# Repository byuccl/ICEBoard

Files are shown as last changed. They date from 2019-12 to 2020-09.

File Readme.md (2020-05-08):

# ICE Board

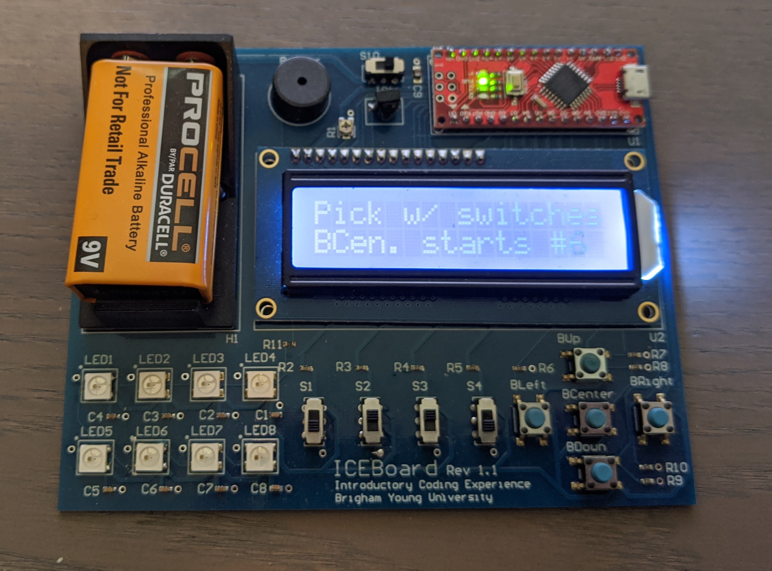
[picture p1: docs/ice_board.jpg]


This repository is for the "Introductory Coding Experience" (ICE) board. The purpose of this board is to provide a simple way for elementry aged students to interact with a simple embedded system by solving simple puzzles or playing simple games using a remote control and the ICE board. The board is based on the Arduino platform.

## Participants
  * Stephanie Ashby (stephoashby@gmail.com) - stephoa
  * Sharisse Poff (sharisse@bevan.us) - sharisse2
  * Elise Hasleton (elhas129@gmail.com) - 
  * Jeff Goeders (jgoeders@byu.edu) - jgoeders
  * Mike Wirthlin (wirthlin@byu.edu) - wirthlin

## Proposed directory structure
  * 'hw' directory for all of the hardware. Include power calculation  spreadsheets.
    * 'pcb' PCB information
    * 'datasheets' : component data sheets,
  * 'src' directory for the Arduino source
  * 'doc' directory for documentation and materials for students

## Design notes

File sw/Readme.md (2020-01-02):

# ICEBoard Software Documents
| Arduino Pin | Type  | Use |
| --- | ----  | --- |
|  1 | D1/TX | Tactile Switch (S5) |
|  2 | D0/RX | IR Receiver (IR1) |
|  3 | RESET |
|  4 | GND |
|  5 | D2 |
|  6 | D3 | NeoPixel (D1 - D8 are controlled with this pin) |
|  7 | D4 | Slide Switch (S1) |
|  8 | D5 | Slide Switch (S2) |
|  9 | D6 | Slide Switch (S3) |
| 10 | D7 | Slide Switch (S4) |
| 11 | D8 |
| 12 | D9 | Buzzer (B1) |
| 13 | D10 | Tactile Switch (S7) |
| 14 | D11 | Tactile Switch (S6) |
| 15 | D12 | Tactile Switch (S8) |
| 16 | D13 | Tactile Switch (S9) |
| 17 | 3V3 | Powers IR Receiver (IR1) |
| 18 | AREF  |
| 19 | A0 | LCD (pin D7) |
| 20 | A1 | LCD (pin D6) |
| 21 | A2 | LCD (pin D5) |
| 22 | A3 | LCD (pin D4) |
| 23 | A4 | LCD (enable pin) |
| 24 | A5 | LCD (reset pin) |
| 25 | A6 |
| 26 | A7 |
| 27 | 5V | Powers neopixels, LCD screen, slide switches, tactile switches (D1 - D8, U2, S1 - S9) |
| 28 | RESET |
| 29 | GND |
| 30 | VIN | Connects to 9V battery |

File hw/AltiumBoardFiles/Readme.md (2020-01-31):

# Revision changes:
## Rev 1.1
- Fixed NeoPixel footprint (Rev 1.0 had the footprint oriented upside down)
- Added 470 ohm resistor between Arduino and first NeoPixel
- Replaced slide switches with larger slide switches
- Added power switch
- Renamed B1 as Buzzer, D1 - D8 as LED1 - LED8, S5 - S9 as BUp, BDown, etc.
- Moved IR1 from pin D0 to pin D2 and S5 from pin D1 to pin D8 to avoid interference with the UART
- Added screw holes for battery holder

# Board Design notes on answered questions:
- There is a software way to turn the NeoPixels on part way so we do not need resistors to dim them.
- All of the traces are routed on the top of the board so the bottom layer can be a ground plane.
- The Arduino cannot supply enough current to have all the LEDs on at full power at the same time.  Make sure software accounts for that.
- The datasheet says that the LCD screen takes 40mA for logic and 30mA for the backlight.  Stephanie measured the currents to be 19mA and 0.6mA.
- [This](https://www.ftdichip.com/Support/Documents/DataSheets/ICs/DS_FT232R.pdf) is the datasheet for the chip on the Arduino Nano that supplies 3.3V.  It looks like the 3.3V pin can supply 50mA.
- It doesn't matter if traces are routed under parts for this board.
- We should not need to specify board thickness in the project's Layer Stack Manager.  It sounds like board thickness is specified separately when ordering the board.
- A 9V battery typically gets up to 500 mAh, which means it wouldn't last very long if we're drawing 500mA at once.  However, if we aren't using all the LEDs at the same time or at maximum brightness it would probably last longer.  Most of what I read suggested drawing less than 100mA, but it sounded like this is just a suggestion to get a longer battery life.  [Here](http://www.techlib.com/reference/batteries.html) is a table I found.
- Usually the buttons will take current when they are pressed if they use a pull up architecture.  Other than a brief transient when the switch is changed, the switches usually don't take any current that is worth keeping track of.

# Board Design questions:
- The LCD instructions say not to connect 5V directly to the backlight terminal.  The part we have probably has a series resistor to account for that, but I read that the backlight needs 3.2V so I wonder if there is a way to power it with the 3.3V pin?  Just a thought if that could help us move some of the current off of the 5V pin.  Stephanie measured the LCD currents and sent me this response: "Measuring the backlight, it was about 19 mA and .6 mA (but that one is with the 1k resistor so...). In any case, I don't know why it is so low, but that is what the multimeter says."  If it really is that low that will help with power consumption as well.
  - I looked into this and I can't find anywhere what resistor is used to limit the voltage to the LCD backlight.
- Is there a better option for RGB LEDs that uses less current?

# Ideas and options:
## RGB LED alternatives to NeoPixels:
1) There are plenty of RGB LEDs that take around 20mA current for each color but they require either four or six logic pins to control.
2) Can use MAX 7219 to control up to 64 LEDs with three Arduino pins: clock, data, latch (330mA)
- Looks like this might only work with an LED matrix
- https://tronixstuff.com/2013/10/11/tutorial-arduino-max7219-led-display-driver-ic/
- brainy-bits.com/how-to-control-max7219-led-matrix/
3) The other programmable LEDs I found also take 50 – 60mA
- https://www.amazon.com/ALITOVE-WS2812B-Individually-Addressable-Waterproof/dp/B00ZHB9M6A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
4) Could use transistors and PWM to control individual LEDS – seems more complicated
- https://arduino.stackexchange.com/questions/29367/individual-control-of-multiple-rgb-leds

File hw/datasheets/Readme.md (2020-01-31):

# ICEBoard Datasheets

## Components

### Arduino Nano

- Purpose: This is the ICEBoard processor.  All of the other components on the board are powered and software-controlled by the Arduino Nano.
- Description: 
- [Website](https://store.arduino.cc/usa/arduino-nano)
- [Datasheet](./nano-user-manual.pdf)
- Notes:

### LCD

- Purpose: 
- Description: Adafruit standard LCD 16x2 + extras - white on blue, through hole
- [Website](https://www.adafruit.com/product/181)
- [Datasheet](./TC1602A-09T.pdf)
- Notes: We are using the TC1602A-09T because it pulls significantly less current than the TC1602A-01T.  The [TC1602A-01T datasheet](./TC1602A-01T) is included in this folder for reference because it includes page 4 (the part drawing), which the TC1602A-09T datasheet is missing.

### NeoPixel

- Purpose: 
- Description: NeoPixel 5050 RGB LED with Integrated Driver Chip, surface mount
- [Website](https://www.adafruit.com/product/1655)
- [Datasheet](./SK6812_LED_datasheet.pdf)
- Notes: NeoPixels require only one digital pin for an entire chain.  Each NeoPixel requires up to 60mA of current.

### Slide Switch

- Purpose: 
- Description: Switch Slide SPDT 300mA 6V, through hole
- [Website](https://www.digikey.com/product-detail/en/apem-inc/MHSS1104/679-1848-ND/1795408)
- [Datasheet](./MHSS1104_drawing.pdf)
- Notes: Rev. 1.0 used the JS202011SCQN part instead.  Its [datasheet](./JS202011SCQN_datasheet.pdf) is still in this folder.

### Tactile Switch

- Purpose: 
- Description: Switch Tactile SPST-NO 0.05A 12V, surface mount
- [Website](https://www.digikey.com/products/en?keywords=CKN10889CT-ND)
- [Datasheet](./PTS645_datasheet.pdf)
- Notes: The footprint will work for a few different colors of push buttons.

### IR Receiver

- Purpose: 
- Description: Sensor Remote Rec 40.0kHz 45M, through hole
- [Website](https://www.digikey.com/products/en?keywords=TSOP38240-ND)
- [Datasheet](./tsop382_datasheet.pdf)
- Notes: This part comes in different frequencies.

### Battery Holder

- Purpose: 
- Description: Battery Holder 9V PC Pin, through hole
- [Website](https://www.digikey.com/products/en?keywords=BH9V-PC-ND)
- [Datasheet](./BH9VPC-datasheet.pdf)
- Notes: 

### Buzzer

- Purpose: 
- Description: Piezo Transducer 5V 5mA 4kHz 75dB@5V, through hole
- [Website](https://www.digikey.com/products/en?keywords=2104-TP124005-2CT-ND)
- [Datasheet](./TP124005-2_drawing.pdf)
- Notes: 

### Potentiometer

- Purpose:
- Description: Trimmer 10k Ohm 0.1W J Lead Top, surface mount
- [Website](https://www.digikey.com/product-detail/en/bourns-inc/TC33X-2-103E/TC33X-103ECT-ND/612911)
- [Datasheet](./tc33_datasheet.pdf)
- Notes: The -2 part has a rotational stop and the -1 part has continous rotation.  The footprints are identical.

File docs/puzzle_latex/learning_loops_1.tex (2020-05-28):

\puzzle{4}{Learning Loops 1}{Easy}

\setlength{\parskip}{0em}
\noindent
\while{\bdown \pressed}
    \assign{\led{1}}{RED}
    \wait{3.0}
    \assign{\led{1}}{OFF}
    \wait{1.0}

    \gap

    \assign{\led{1}}{RED}
    \wait{3.0}
    \assign{\led{1}}{OFF}
    \wait{1.0}

    \gap

    \assign{\led{1}}{RED}
    \wait{3.0}
    \assign{\led{1}}{OFF}
    \wait{1.0}

\whileend

\programend

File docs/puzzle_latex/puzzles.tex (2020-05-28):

\documentclass[]{article}

\usepackage[margin=1in]{geometry}
\usepackage{fmtcount}
\usepackage{xcolor}
\usepackage{lmodern}

\newcommand{\puzzle}[3]{%
    \noindent
    \rule{\textwidth}{2pt}   
    \begin{center} 
        { \large Program \##1: #2  \\ \vspace{0.05in}
        Set switches to: \padzeroes[4]\binarynum{#1} \\ \vspace{0.05in}
        (\textit{#3}) }
    \end{center}   
    \rule{\textwidth}{2pt}   %
}

\newcommand{\incindent}{\addtolength\parindent{20pt}}
\newcommand{\decindent}{\addtolength\parindent{-20pt}}

\newcommand{\gap}{\vspace{0.1in}}

\newcommand{\while}[1]{{\color{blue}\textbf{while: }}#1 \{ \incindent \par}
\newcommand{\whileend}{\decindent \par\}}

\newcommand{\wait}[1]{\textbf{wait} #1 seconds \par}

\newcommand{\assign}[2]{ #1 $\leftarrow$ #2 \par}

\newcommand{\lcd}{{\color{purple}\textbf{LCD screen}}}
\newcommand{\printtolcd}[1]{Print `#1' to \lcd}

\newcommand{\bdown}{{\color{purple}\textbf{BDown }}}

\newcommand{\led}[1]{{\color{purple}\textbf{led#1}}}

\newcommand{\pressed}{is pressed}
\newcommand{\notpressed}{is not pressed}

\newcommand{\programend}{\gap \gap Play beep sound \\ \printtolcd{You win} }
\begin{document}

\ttfamily
\setlength{\parindent}{0pt}

\input{learning_loops_1.tex}

\end{document}

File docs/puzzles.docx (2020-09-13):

# Puzzle #1

while [led1, led2, led3, led4] is NOT [BLUE, YELLOW, GREEN, PURPLE]:

while BCenter is not pressed:

if S1 is up:

led8.red = ON

else:

led8.red = OFF

if S2 is up:

led8.green = ON

else:

led8.green = OFF

if S3 is up:

led8.blue = ON

else:

led8.blue = OFF

led4 = led2

led2 = led3

led3 = led1

led0 = led8

while BCenter is pressed:

do nothing

Play beep sound

Print “You win” on LCD screen

# Puzzle #2

A = 0;

B = 0;

Print A, “+”, B, “=”, A+B on LCD screen

while A + B != 10 or A < 2 or B < 2:

if BUp is pressed and BRight is pressed:

A = A + 1

clear LCD screen

led1 = BLUE;

delay(1.0);

led1 = OFF;

Print A, “+”, B, “=”, A+B on LCD screen

if BCenter is pressed and BDown is pressed:

B = B + 1

clear LCD screen

led8 = GREEN;

delay(1.0);

led8 = OFF;

Print A, “+”, B, “=”, A+B on LCD screen

delay(1.0);

Play beep sound

Print “You win” on LCD screen

# Puzzle #3

loop {

led1 = YELLOW

wait 5.0 seconds

led1 = OFF

if S4 is UP:

led1 = RED;

loop {

if S4 is DOWN:

exit loop

}

else:

wait 0.5 seconds

if S4 is UP:

exit loop

}

Play beep sound

Print “You win” on LCD screen

# #4 (0100) – Learning Loops 1

while BDown is not pressed:

led1 = RED

wait 3.0 seconds

led1 = OFF

wait 1.0 seconds

led1 = BLUE

wait 3.0 seconds

led1 = OFF

wait 1.0 seconds

led1 = GREEN

wait 3.0 seconds

led1 = OFF

wait 1.0 seconds

Play beep sound

Print “You win” on LCD screen

Question: Why doesn’t the program end as soon as you press BDown?

# #5 (0101) – Learning Ifs 1

loop forever:

if BLeft is pressed:

led5 = RED

led6 = ORANGE

led7 = YELLOW

if BRight is pressed:

exit loop

else

led5 = BLUE

led6 = AQUA

led7 = GREEN

Play beep sound

Print “You win” on LCD screen

Question: Why doesn’t the program end if you only press BRight?

# #6 (0110) – Learning Loops 2

X = 0

led1 = GREEN

while X < 10:

Wait for BCenter to be pressed

Print “X is ” on LCD screen

Print X on LCD screen

LED2 = LED3

LED3 = LED4

LED4 = LED8

LED8 = LED7

LED7 = LED6

LED6 = LED5

LED5 = LED1

LED1 = OFF

X = X + 1

Play beep sound

Print “You win” on LCD screen

Question: What’s the value of X when the program ends?

Challenge: Explain why two LEDs turn on at the same time, but only once.

# #7 (0111) – Learning Loops 3

led1 = GREEN

led2 = GREEN

led3 = GREEN

led4 = GREEN

BUp = 1;

BRight = 2;

BDown = 3;

BLeft = 4;

button = (press a button)

for (button) number of times, turn on one LED

led4 = PURPLE

led3 = PURPLE

led2 = PURPLE

led1 = PURPLE

Play beep sound

Print “You win” on LCD screen

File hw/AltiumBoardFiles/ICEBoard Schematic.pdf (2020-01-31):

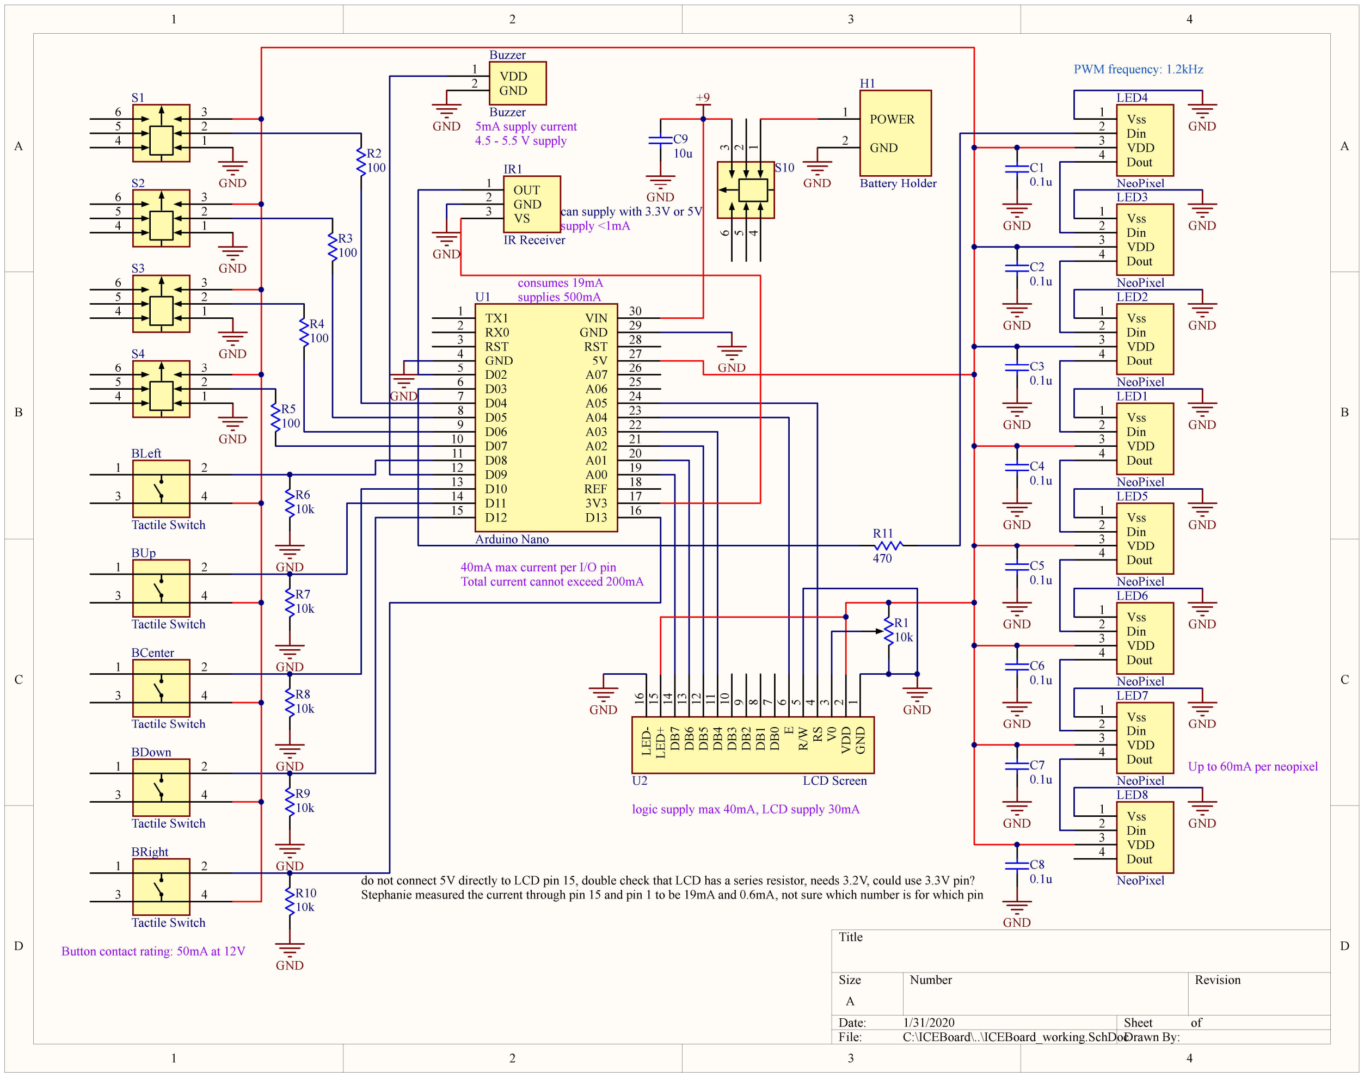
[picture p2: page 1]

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
Title

Size | Number | | Revision
A
Date: | 1/31/2020 | Sheet | of
File: | C:\ICEBoard\..\ICEBoard_working.SchDocDrawn By:
VIN | 30
GND | 29
RST | 28
5V | 27
A07 | 26
A06 | 25
A05 | 24
A04 | 23
A03 | 22
A02 | 21
A01 | 20
A00 | 19
REF | 18
3V3 | 17
D13 | 16 D12 15

TX1 1
RX0 2

GND 4
D02 5
D03 6

RST 3

D04 7
D05 8
D06 9
D07 10
D08 11
D10 13 D09 12

D11 14

U1

Arduino Nano

GND

+9
Vss 1
Din 2

Dout 4

VDD 3

LED4

NeoPixel

Vss 1
Din 2

Dout 4

VDD 3

LED3

NeoPixel

GND

GND

logic supply max 40mA, LCD supply 30mA

do not connect 5V directly to LCD pin 15, double check that LCD has a series resistor, needs 3.2V, could use 3.3V pin?

PWM frequency: 1.2kHz

40mA max current per I/O pin

consumes 19mA

Up to 60mA per neopixel LED⁻ ¹⁶ LED⁺ ¹⁵ | GND

## 1 VDD

### 2 RS

## 4 R/W

### 5 E

### 6 V0

### 3 DB0

## 7 DB1

## 8 DB2

### 9 DB3 10 DB4 11 DB6 13 DB5 12 DB7 14

U2 | LCD Screen

GND

Button contact rating: 50mA at 12V

Vss 1
Din 2

Dout 4

VDD 3

LED2

NeoPixel

Vss 1
Din 2

Dout 4

VDD 3

LED1

NeoPixel

GND

GND

5mA supply current
4.5 - 5.5 V supply

Vss 1
Din 2

Dout 4

VDD 3

LED5

NeoPixel

Vss 1
Din 2

Dout 4

VDD 3

LED6

NeoPixel

Vss 1
Din 2

Dout 4

VDD 3

LED7

NeoPixel

Vss 1
Din 2

Dout 4

VDD 3

LED8

NeoPixel

GND

GND

GND

GND

POWER 1

GND 2

H1

GND Battery Holder

GND

C1
0.1u

C2
0.1u

C3
0.1u

C4
0.1u

C5
0.1u

C6
0.1u

C7
0.1u

C8
0.1u

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
VDD 1
GND 2

Buzzer

Buzzer
GND

can supply with 3.3V or 5V

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
supplies 500mA

R4
100

R5
100

R2
100

R3
100 GND

supply <1mA

OUT 1
GND 2
VS 3

IR1

IR Receiver

Stephanie measured the current through pin 15 and pin 1 to be 19mA and 0.6mA, not sure which number is for which pin

Total current cannot exceed 200mA

GND

GND

GND

GND

1

3 4

2

BLeft

Tactile Switch

1

3 4

2

BUp

Tactile Switch

1

3 4

2

BCenter

Tactile Switch

1

3 4

2

BDown

Tactile Switch

1

3 4

2

BRight

Tactile Switch

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
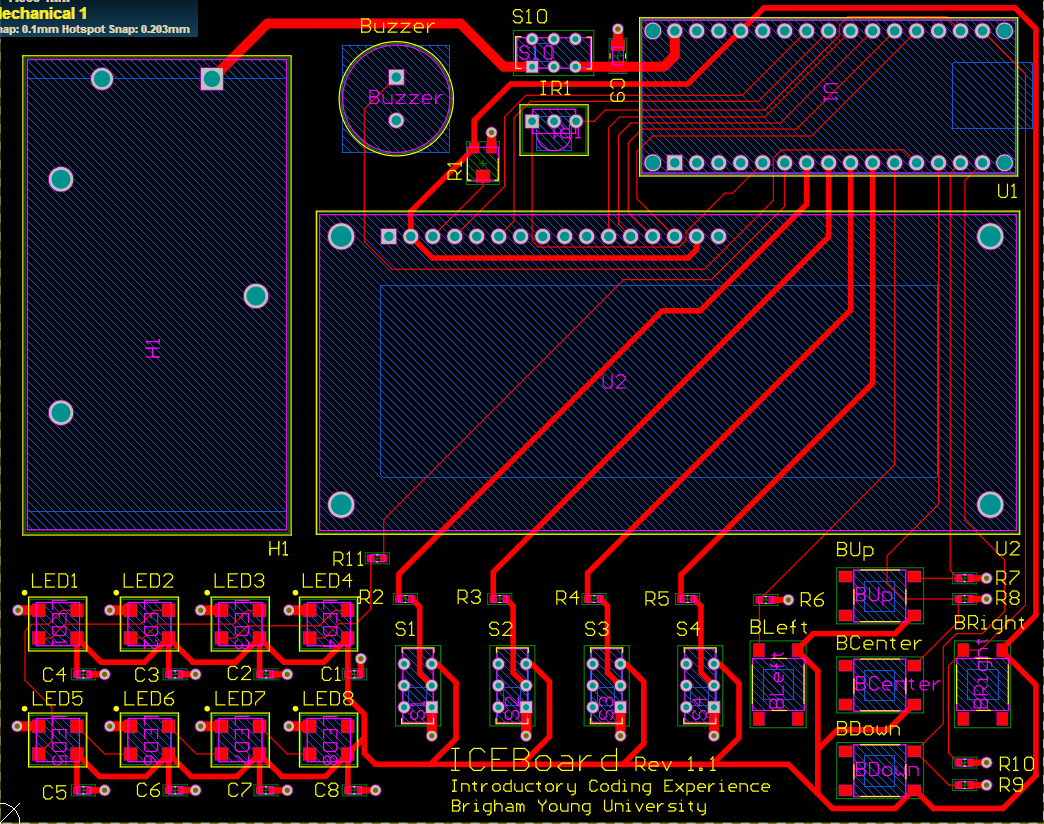
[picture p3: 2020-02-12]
hw/AltiumBoardFiles/ICEBoard PCB Layout (ground plane hidden).PNG

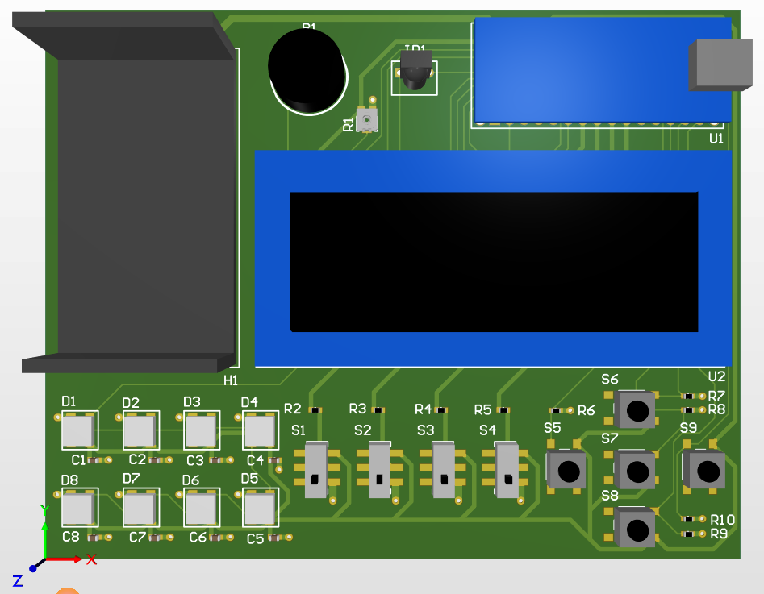
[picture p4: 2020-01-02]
hw/AltiumBoardFiles/ICEBoard PCB Layout 3D-1.PNG

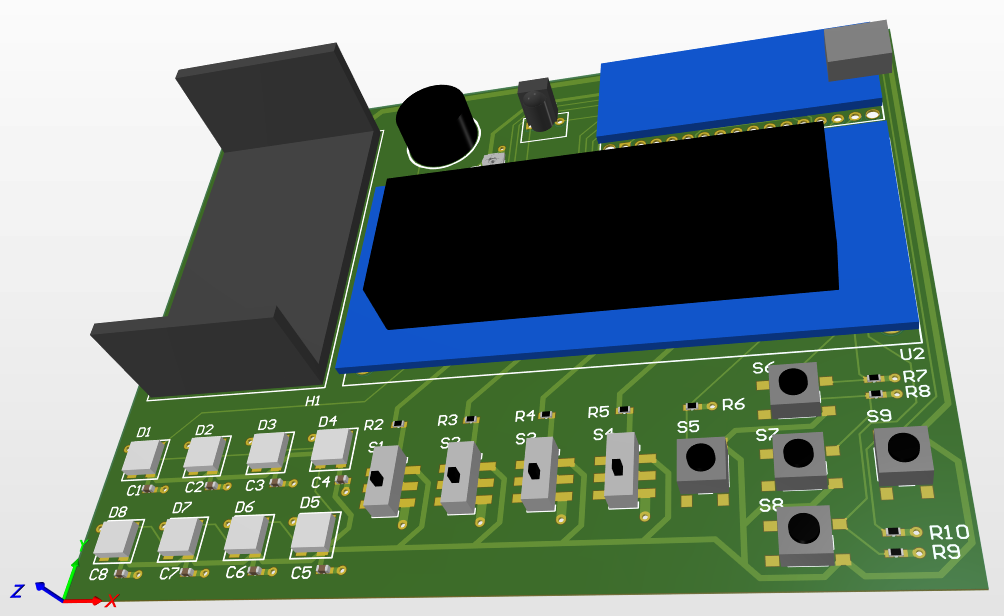
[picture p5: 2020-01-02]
hw/AltiumBoardFiles/ICEBoard PCB Layout 3D-2.PNG

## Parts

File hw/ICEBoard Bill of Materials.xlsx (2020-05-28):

Type | Value | Manufacturer | Manufacturer Part Number | Description | Where Used | Unit Price | Quantity | Total Price | Digi-Key Part Number | Link
Arduino | Nano | Arduino |  |  | U1 | $4.00 | 1 | $4.00 | -
LCD screen |  | Adafruit |  | Standard LCD 16x2 + extras - white on blue | U2 | $9.95 | 1 | $9.95 | 1528-1502-ND | https://www.digikey.com/product-detail/en/adafruit-industries-llc/181/1528-1502-ND/5774228 | $248.75
RGB LED |  | Adafruit |  | NeoPixel 5050 RGB LED with Integrated Driver Chip - 10 pack | LED1, LED2, LED3, LED4, LED5, LED6, LED7, LED8 | $0.45 | 8 | $3.60 | 1528-1104-ND | https://www.digikey.com/product-detail/en/adafruit-industries-llc/1655/1528-1104-ND/5154679 | $90.00
Slide Switch | SPDT | APEM | MHSS1104 | SWITCH SLIDE SPDT 300MA 6V | S1, S2, S3, S4, S10 | $0.49 | 5 | $2.48 | 679-1848-ND | https://www.digikey.com/product-detail/en/MHSS1104/679-1848-ND/1795408/?itemSeq=319915833 | $61.88
Tactile Switch | SPST-NO | C&K | PTS645SM50SMTR92 LFS | SWITCH TACTILE SPST-NO 0.05A 12V | BLeft, BUp, BCenter, BDown, BRight | $0.22 | 5 | $1.10 | CKN10889CT-ND | https://www.digikey.com/product-detail/en/c-k/PTS645SM50SMTR92-LFS/CKN10889CT-ND/3861376 | $27.47
IR Receiver | 40kHz | Vishay | TSOP38238 | SENSOR REMOTE REC 40.0KHz 45M | IR1 | $0.76 | 1 | $0.76 | TSOP38240-ND | https://www.digikey.com/products/en?keywords=TSOP38240-ND | $18.90
Battery Holder | 9V holder | MPD | BH9VPC | BATTERY HOLDER 9V PC PIN | H1 | $1.70 | 1 | $1.70 | BH9V-PC-ND | https://www.digikey.com/products/en?keywords=BH9VPC | $42.43
Resistor | 10k | Bourns | TC33X-2-103E | TRIMMER 10K OHM 0.1W J LEAD TOP | R1 | $0.25 | 1 | $0.25 | TC33X-103ECT-ND | https://www.digikey.com/product-detail/en/bourns-inc/TC33X-2-103E/TC33X-103ECT-ND/612911 | $6.26
Resistor | 100 | Yageo | RC0603FR-07100RL | RES SMD 100 OHM 1% 1/10W 0603 | R2, R3, R4, R5 | $0.01 | 4 | $0.04 | 311-100HRCT-ND | https://www.digikey.com/product-detail/en/%E5%9E%88%ED%9B%87/RC0603FR-07100RL/311-100HRCT-ND/729835 | $0.94
Resistor | 10k | Yageo | RC0603FR-0710KL | RES SMD 10K OHM 1% 1/10W 0603 | R6, R7, R8, R9, R10 | $0.02 | 5 | $0.11 | 311-10.0KHRCT-ND | https://www.digikey.com/product-detail/en/%E5%9E%88%ED%9B%87/RC0603FR-0710KL/311-10-0KHRCT-ND/729827 | $2.88
Resistor | 470 | Yageo | RC0603FR-07470RL | RES SMD 470 OHM 1% 1/10W 0603 | R11 | $0.02 | 1 | $0.02 | 311-470HRCT-ND | https://www.digikey.com/product-detail/en/yageo/RC0603FR-07470RL/311-470HRCT-ND/730203 | $0.57
Capacitor | 0.1u | Kemet | C0603C104M4RACTU | CAP CER 0.1UF 16V X7R 0603 | C1, C2, C3, C4, C5, C6, C7, C8 | $0.02 | 8 | $0.13 | 399-1099-1-ND | https://www.digikey.com/product-detail/en/kemet/C0603C104M4RACTU/399-1099-1-ND/411374 | $3.22
Capacitor | 10u | Kemet | CL21A106KPFNNNG | CAP CER 10UF 10V X5R 0805 | C9 | $0.08 | 1 | $0.08 | 399-4925-1-ND | https://www.digikey.com/product-detail/en/kemet/C0805C106K8PACTU/399-4925-1-ND/1090920 | $2.05
Buzzer | 4kHz | DB Unlimited | TP124005-2 | PIEZO TRANSDUCER 5V 5mA 4kHz 75dB@5V, through hole | Buzzer | $0.65 | 1 | $0.65 | 2104-TP124005-2CT-ND | https://www.digikey.com/product-detail/en/db-unlimited/TP124005-2/2104-TP124005-2CT-ND/10288171 | $16.35
 |  |  |  |  |  |  | Total | $24.87

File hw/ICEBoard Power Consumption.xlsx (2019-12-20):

Part | Voltage supply | Voltage needed | Current produced (mA) | Current consumption (mA) | Quantity on board | Total consumption (mA)
Battery | 9V
Arduino Nano |  | 7-12V | 500 | 19 | 1 | 19 | power with Arduino 5V pin
NeoPixel |  | 5V |  | 60 | 8 | 480 | power with Arduino 5V pin
LCD screen |  | 5V |  | 70 | 1 | 70 | power with Arduino 5V pin
Slide Switch |  |  |  |  |  |  | power with Arduino 5V pin
Tactile Switch |  |  |  |  |  |  | power with Arduino 5V pin
 |  |  |  |  | TOTAL CURRENT NEEDED from 5V pin: | 569
IR receiver |  | 2.5-5.5V |  | 3 | 1 | 3 | power with Arduino 3.3V pin
Buzzer |  | 4.5-5.5V |  | 5 | 1 | 5 | power with Arduino I/O pin

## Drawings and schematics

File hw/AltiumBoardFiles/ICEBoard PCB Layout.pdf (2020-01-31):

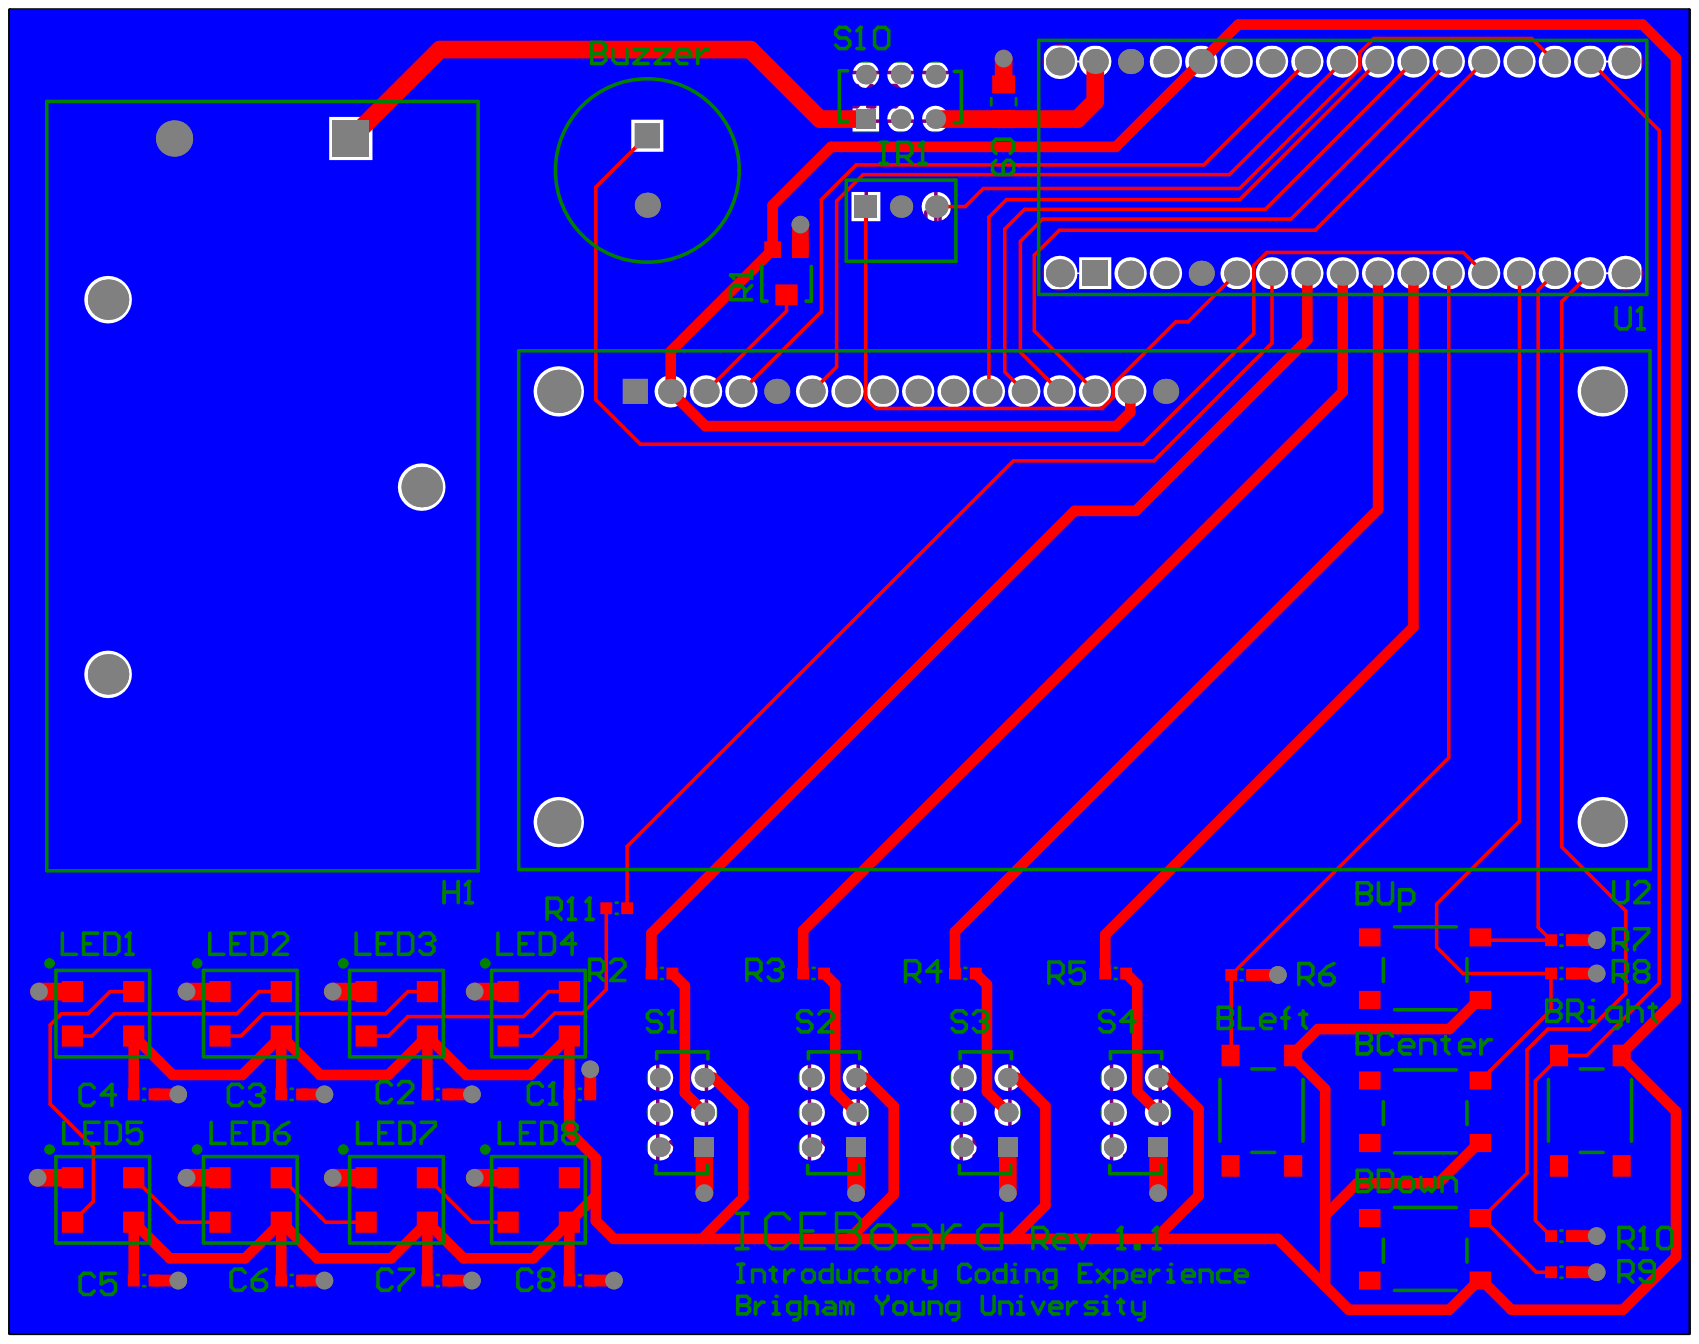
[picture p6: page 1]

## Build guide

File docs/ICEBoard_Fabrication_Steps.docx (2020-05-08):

ICE Board Fabrication Steps

1. Apply solder paste
2. Add surface mount components:
- Add Push Buttons
- 10k Trimmer: R1
- 100 Ohm: R2, R3, R4, R5
- 10k Ohm: R6, R7, R8, R9, R10
- 470 Ohm: R11
- 0.1uF: C1, C2, C3, C4, C5, C6, C7, C8
- 10uF: C9
3. Bake in oven
4. Solder remaining components:
  - Arduino
  - LCD Screen
  - Neopixel LEDs
  - Slide switches
  - Battery holder
  - Buzzer

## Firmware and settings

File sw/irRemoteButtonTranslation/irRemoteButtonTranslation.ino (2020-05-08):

/**
 * DecodeIR.ino
 * 
 * Uses IRremote library to take in NEC codes and translates them to button values 
 * 
 * Does not currently debounce buttons which causes issue with printing consistantly to the screen
 * 
 * Current issue with other ir interference, prints "Not a button detected" when detected
 * This interference can be caused by phone cameras that use IR sensors, the receiver picks
 * the hex codes up and tries to translate them.
 * 
 */

#include <IRremote.h>
#include <LiquidCrystal.h>

#define VOLUME_MINUS_TEXT "Vol-"
#define PLAY_PAUSE_TEXT ">||"
#define VOLUME_PLUS_TEXT "Vol+"
#define SETUP_TEXT "Setup"
#define UP_TEXT "^"
#define STOP_MODE_TEXT "Stop/Mode"
#define LEFT_TEXT "<"
#define ENTER_SAVE_TEXT "Enter/Save"
#define RIGHT_TEXT ">"
#define ZERO_TEXT "0"
#define DOWN_TEXT "V"
#define BACK_ARROW_TEXT "<--"
#define ONE_TEXT "1"
#define TWO_TEXT "2"
#define THREE_TEXT "3"
#define FOUR_TEXT "4"
#define FIVE_TEXT "5"
#define SIX_TEXT "6"
#define SEVEN_TEXT "7"
#define EIGHT_TEXT "8"
#define NINE_TEXT "9"

#define VOLUME_MINUS_HEX 0x00FF
#define PLAY_PAUSE_HEX 0x807F
#define VOLUME_PLUS_HEX 0x40BF
#define SETUP_HEX 0x20DF
#define UP_HEX 0xA05F
#define STOP_MODE_HEX 0x609F
#define LEFT_HEX 0x10EF
#define ENTER_SAVE_HEX 0x906F
#define RIGHT_HEX 0x50AF
#define ZERO_HEX 0x30CF
#define DOWN_HEX 0xB04F
#define BACK_ARROW_HEX 0x708F
#define ONE_HEX 0x08F7
#define TWO_HEX 0x8877
#define THREE_HEX 0x48B7
#define FOUR_HEX 0x28D7
#define FIVE_HEX 0xA857
#define SIX_HEX 0x6897
#define SEVEN_HEX 0x18E7
#define EIGHT_HEX 0x9867
#define NINE_HEX 0x58A7

// Pin on board with IR sensor
int IR_INPUT_PIN = 2;

LiquidCrystal lcd(A5, A4, A3, A2, A1, A0);
IRrecv receivedInput(IR_INPUT_PIN);
decode_results raw_remote_codes;


uint16_t currentCode = 0;
uint16_t previousCode = 0;

//Decodes the received hex as a numerical value. Non-numeric values return as 10
int8_t decodeNumber(uint16_t code);

//Decodes the received hex and tells which button was pressed in a string
String getButtonText(uint16_t code);

void setup() {
  receivedInput.enableIRIn(); // Start the receiver
}

void loop() {
  if (receivedInput.decode(&raw_remote_codes)) {
    previousCode = currentCode;
    currentCode = raw_remote_codes.value;
    lcd.clear();
    lcd.print(getButtonText(currentCode));
    if (decodeNumber(currentCode) != -1)
    {
      //Do something if button has been pressed and is valid
    }
    else
    { 
      // If button has been pressed and is not valid
      
      // Shows if non-remote value has been misidentified
      lcd.clear();
      lcd.print("Not a button detected");
    }
    receivedInput.resume(); // Receive the next value
  }
}

//Returns the text of the button the remote is sending
String getButtonText(uint16_t code)
{
    String str;
// Prints raw hex code of the button press
//  if (code != 0xFFFF)
//  {
//    Serial.print(code, HEX);
//    Serial.print("\t");
//  }
  switch (code) {
    case VOLUME_MINUS_HEX: 
      str = VOLUME_MINUS_TEXT;
      break;
    case PLAY_PAUSE_HEX:
      str = PLAY_PAUSE_TEXT;
      break;
    case VOLUME_PLUS_HEX:
      str = VOLUME_PLUS_TEXT;
      break;
    case SETUP_HEX:
      str = SETUP_TEXT;
      break;
    case UP_HEX:
      str = UP_TEXT;
      break;
    case STOP_MODE_HEX:
      str = STOP_MODE_TEXT;
      break;
    case LEFT_HEX:
      str = LEFT_TEXT;
      break;
    case ENTER_SAVE_HEX:
      str = ENTER_SAVE_TEXT;
      break;
    case RIGHT_HEX:
      str = RIGHT_TEXT;
      break;
    case ZERO_HEX:
      str = ZERO_TEXT;
      break;
    case DOWN_HEX:
      str = DOWN_TEXT;
      break;
    case BACK_ARROW_HEX:
      str = BACK_ARROW_TEXT;
      break;
    case ONE_HEX:
      str = ONE_TEXT;
      break;
    case TWO_HEX:
      str = TWO_TEXT;
      break;
    case THREE_HEX:
      str = THREE_TEXT;
      break;
    case FOUR_HEX:
      str = FOUR_TEXT;
      break;
    case FIVE_HEX:
      str = FIVE_TEXT;
      break;
    case SIX_HEX:
      str = SIX_TEXT;
      break;
    case SEVEN_HEX:
      str = SEVEN_TEXT;
      break;
    case EIGHT_HEX:
      str = EIGHT_TEXT;
      break;
    case NINE_HEX:
      str = NINE_TEXT;
      break;
    default:
      break;
  }
  return str;
}

//Returns int translation of what the remote is sending
int8_t decodeNumber(uint16_t code)
{
  if (code != 0xFFFF)
  {
    switch (code) {
      case VOLUME_MINUS_HEX:
      case PLAY_PAUSE_HEX:
      case VOLUME_PLUS_HEX:
      case SETUP_HEX:
      case UP_HEX:
      case STOP_MODE_HEX:
      case LEFT_HEX:
      case ENTER_SAVE_HEX:
      case RIGHT_HEX:
      case DOWN_HEX:
      case BACK_ARROW_HEX:
        return 10;
      case ZERO_HEX:
        return 0;
      case ONE_HEX:
        return 1;
      case TWO_HEX:
        return 2;
      case THREE_HEX:
        return 3;
      case FOUR_HEX:
        return 4;
      case FIVE_HEX:
        return 5;
      case SIX_HEX:
        return 6;
      case SEVEN_HEX:
        return 7;
      case EIGHT_HEX:
        return 8;
      case NINE_HEX:
        return 9;
      default:
        return -1;
    }
  }
}

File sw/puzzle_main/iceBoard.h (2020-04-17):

#ifndef __PUZZLE_MAIN_H__
#define __PUZZLE_MAIN_H__

#include <Adafruit_NeoPixel.h>
#include <LiquidCrystal.h>

extern Adafruit_NeoPixel leds;
extern LiquidCrystal lcd;

#define BUZZER_PIN 9

#define NEOPIXEL_PIN 3
#define LED_COUNT 8

#define S1_PIN 4
#define S2_PIN 5
#define S3_PIN 6
#define S4_PIN 7

#define BU_PIN 11
#define BL_PIN 8
#define BC_PIN 10
#define BD_PIN 12
#define BR_PIN 13

#define LCD_DB7_PIN A0
#define LCD_DB6_PIN A1
#define LCD_DB5_PIN A2
#define LCD_DB4_PIN A3
#define LCD_E_PIN A4
#define LCD_RS_PIN A5

#define IR_PIN 2

#define BRIGHTNESS 10

#define OFF (0)
#define BLUE (BRIGHTNESS)
#define GREEN (BRIGHTNESS << 8)
#define RED (((uint32_t)BRIGHTNESS) << 16)
#define YELLOW (RED | GREEN)
#define PURPLE (RED | BLUE)
#define AQUA (GREEN | BLUE)
#define WHITE (RED | GREEN | BLUE)
#define ORANGE (RED | ((GREEN) / 2))

#define LED1 3
#define LED2 2
#define LED3 1
#define LED4 0
#define LED5 4
#define LED6 5
#define LED7 6
#define LED8 7

Adafruit_NeoPixel leds(LED_COUNT, NEOPIXEL_PIN, NEO_GRB + NEO_KHZ800);
LiquidCrystal lcd(LCD_RS_PIN, LCD_E_PIN, LCD_DB4_PIN, LCD_DB5_PIN, LCD_DB6_PIN, LCD_DB7_PIN);

void iceboard_setup_io()
{
    pinMode(S1_PIN, INPUT);
    pinMode(S2_PIN, INPUT);
    pinMode(S3_PIN, INPUT);
    pinMode(S4_PIN, INPUT);

    pinMode(BU_PIN, INPUT);
    pinMode(BL_PIN, INPUT);
    pinMode(BC_PIN, INPUT);
    pinMode(BD_PIN, INPUT);
    pinMode(BR_PIN, INPUT);

    lcd.begin(16, 2);
    Serial.begin(9600);

    leds.begin();
    leds.clear();
}

void puzzle_done();
uint32_t pack_color(uint8_t red, uint8_t green, uint8_t blue);

#endif

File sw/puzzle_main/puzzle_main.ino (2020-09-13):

#include "iceBoard.h"
#include "puzzles.h"

void setup()
{
    iceboard_setup_io();
    turn_off_leds();
}

void loop()
{
    lcd.setCursor(0, 0);
    lcd.print("Pick w/ switches");
    lcd.setCursor(0, 1);

    int puzzle_idx = digitalRead(S1_PIN) * 8 + digitalRead(S2_PIN) * 4 + digitalRead(S3_PIN) * 2 + digitalRead(S4_PIN);

    lcd.print("BCen. starts #  ");
    lcd.setCursor(14, 1);
    lcd.print(puzzle_idx);

    if (digitalRead(BC_PIN))
    {
        lcd.clear();
        switch (puzzle_idx)
        {
        case 1:
            puzzle1();
            break;
        case 2:
            puzzle2();
            break;
        case 3:
            puzzle3();
            break;
        case 4:
            lcd.print("Program #");
            lcd.print(puzzle_idx);
            lcd.setCursor(0, 1);
            lcd.print("Learning Loops 1");
            loops1();
            break;
        case 5:
            lcd.print("Program #");
            lcd.print(puzzle_idx);
            lcd.setCursor(0, 1);
            lcd.print("Learning Ifs 1");
            ifStatement1();
            break;
        case 6:
            lcd.print("Program #");
            lcd.print(puzzle_idx);
            lcd.setCursor(0, 1);
            lcd.print("Learning Loops 2");
            loops2();
            break;
        case 7:
            lcd.print("Program #");
            lcd.print(puzzle_idx);
            lcd.setCursor(0, 1);
            lcd.print("Learning Loops 3");
            loops3();
            break;
        }
    }
}

void puzzle_done()
{

    // Play noise
    analogWrite(BUZZER_PIN, 128);
    delay(500);
    analogWrite(BUZZER_PIN, 0);

    lcd.clear();
    lcd.print("You win");
    lcd.setCursor(0, 1);
    lcd.print("Press BCenter");
    while (!digitalRead(BC_PIN))
        ;
    while (digitalRead(BC_PIN))
        ;
    turn_off_leds();
}

uint32_t pack_color(uint8_t red, uint8_t green, uint8_t blue)
{
    return ((uint32_t)red << 16) | ((uint32_t)green << 8) | ((uint32_t)blue);
}

void turn_off_leds()
{
    for (int i = 0; i < 7; i++)
        leds.setPixelColor(i, OFF);
    leds.show();
}

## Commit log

2019-12-20 removed comments
    [ICEBoard.SchDoc]
2019-12-21 Adding Altium files from local computer
    [ICEBoard.PcbDoc, ICEBoard.PrjPcb, ICEBoard.SchDoc]
2019-12-21 reorganized Altium files
    [ArduinoNano.PcbLib, ArduinoNano.SchLib, BH9VPC.PcbLib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]
2019-12-21 Added note to LCD voltage question
2019-12-31 clarified schematic symbols and rewired PCB to match
    [Capacitor1608.PcbLib, ICEBoard.PcbDoc, ICEBoard.PrjPcb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]
2020-01-02 moved buzzer and ir sensor from analog to digital pins, added potentiometer
    [ICEBoard.PcbDoc, ICEBoard.PrjPcb, ICEBoard.SchDoc]
2020-01-02 added 10uF capacitor
    [ICEBoard Bill of Materials.xlsx, ICEBoard.PcbDoc, ICEBoard.SchDoc]
2020-01-07 modified footprint
    [Capacitor2012.PcbLib]
2020-01-07 added Gerber files
    [ICEBoard.PcbDoc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]
2020-01-19 fixed NeoPixel footprints
    [ICEBoard Bill of Materials.xlsx, ICEBoard.PcbDoc, ICEBoard.PrjPcb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]
2020-01-21 Update slide switch and added links
    [ICEBoard Bill of Materials.xlsx]
2020-01-22 working on rev 1.1 changes
    [BH9VPC.PcbLib, ICEBoard.PcbDoc, ICEBoard.PrjPcb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]
2020-01-22 Add files via upload
    Simple program to show how for loops work. Current purpose is to flip a string of chars and see what different code does.
    [Multiple_Choice_Challenge.ino]
2020-01-24 Updates to test code
    [ICEBoard Bill of Materials.xlsx]
2020-01-24 Add full board test
2020-01-31 made changes for Rev 1.1
    [ICEBoard Bill of Materials.xlsx, ICEBoard_working.PcbDoc, ICEBoard_working.SchDoc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]
2020-01-31 finished Rev 1.1 modifications
    [BH9VPC.PcbLib, ICEBoard Bill of Materials.xlsx, ICEBoard.PrjPcb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]
2020-02-03 updated board screenshot, changed schematic and layout names
    [ICEBoard.PrjPcb, ICEBoard_working_copy.PcbDoc, ICEBoard_working_copy.SchDoc]
2020-02-03 generated gerber files for rev 1.1
    [ICEBoard.PrjPcb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]
2020-03-06 Update BOM
    [ICEBoard Bill of Materials.xlsx]
2020-03-10 Updating board test program
2020-04-22 Updating BOM
    [ICEBoard Bill of Materials.xlsx]
2020-04-23 Add files via upload
    Uses IRremote library to take in NEC codes and translates them to button values
    Does not currently debounce buttons which causes issue with printing consistently to the screen
    Current issue with other IR interference, prints "Not a button detected" when detected. This interference can be caused by phone cameras that use IR sensors, the receiver picks the hex codes up and tries to translate them. To see this occur, wave phone camera in front of IR Sensor or angle remote away from sensor while pressing buttons
    [irRemoteButtonTranslation.ino]
2020-04-23 Added IRremote library
    This is the library used for receiving IR remote codes to the board. The board only uses the NEC protocol and is only set to receive, but this can be changed in the IRremote.h file. See irRemoteButto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
2020-04-23 bom updates
    [ICEBoard Bill of Materials.xlsx]
